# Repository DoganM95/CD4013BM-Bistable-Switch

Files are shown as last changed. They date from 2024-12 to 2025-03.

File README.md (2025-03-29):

# Intro

A pcb with a single button, which on each press toggles a mosfet's output on/off, acting like a mechanical switch. 

## PCB

<table>
  <tr>
    <td>
      PCB Top View
    </td>
    <td>
      PCB Bottom View
    </td>
    <td>
      PCB Top View
    </td>
    <td>
      PCB Top View
    </td>
  </tr>
</table>

## Specs

- Current troughput theoretically: around 10A
- PCB input voltage: 3.0V - 5.0V
- Thicc exposed mosfet traces to create solder wires

## Properties

- Power consumption
  - Switched off:
    - 0.0 uA @ 2.5 V (= less than 100 nA)
    - 4 uA @ 4.2 V
    - 25 uA @ 5.0 V
  - Switched on:
    - 240 uA @ 2.5V
    - 500 uA @ 4.2V
    - 500 uA @ 5.0 V
- Initial state is off
- Two n-channel mosfets in parallel for high current support
- Green status led (optional)
- Debounced button

## BOM
R1: 0805 sized, 10k
R2: 0805 sized, 10k
R3: 0805 sized, 10k
C1: 0805 sized, 100nF
C2: 0805 sized, 100nF
U1: SOIC14 package, CD4013BM
U2: sot23-3 package, AO3400
U3: sot23-3 package, AO3400
S1: Tactile switch CK (Metal shell)
D1: 3528 sized, RGB led with common VCC

## Usage

- Connect e.g. a li-ion battery's GND to the pcb's GND
- Connect li-ion VCC to pcb's VCC
- Connect li-ion VCC to e.g. a motor's VCC
- Connect pcb's DR to motor's GND

## Schematic



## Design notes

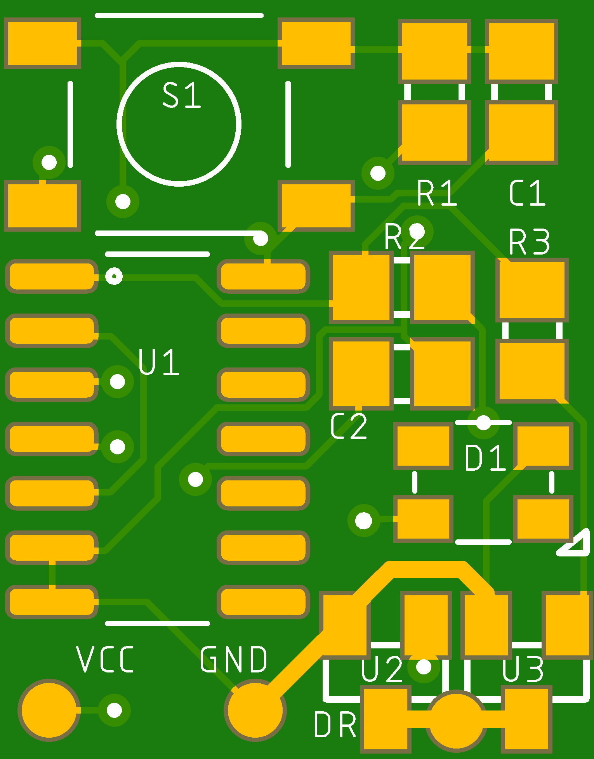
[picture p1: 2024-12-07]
assets/bistable-switch_top.png

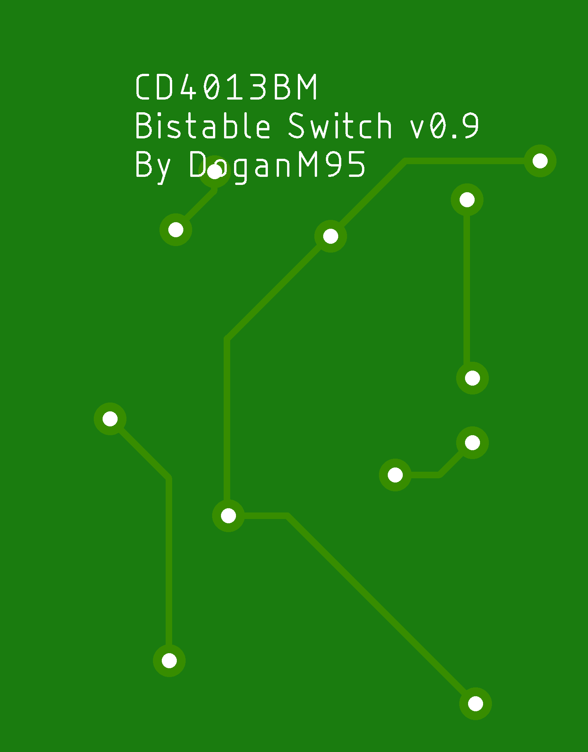
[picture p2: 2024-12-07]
assets/bistable-switch_bottom.png

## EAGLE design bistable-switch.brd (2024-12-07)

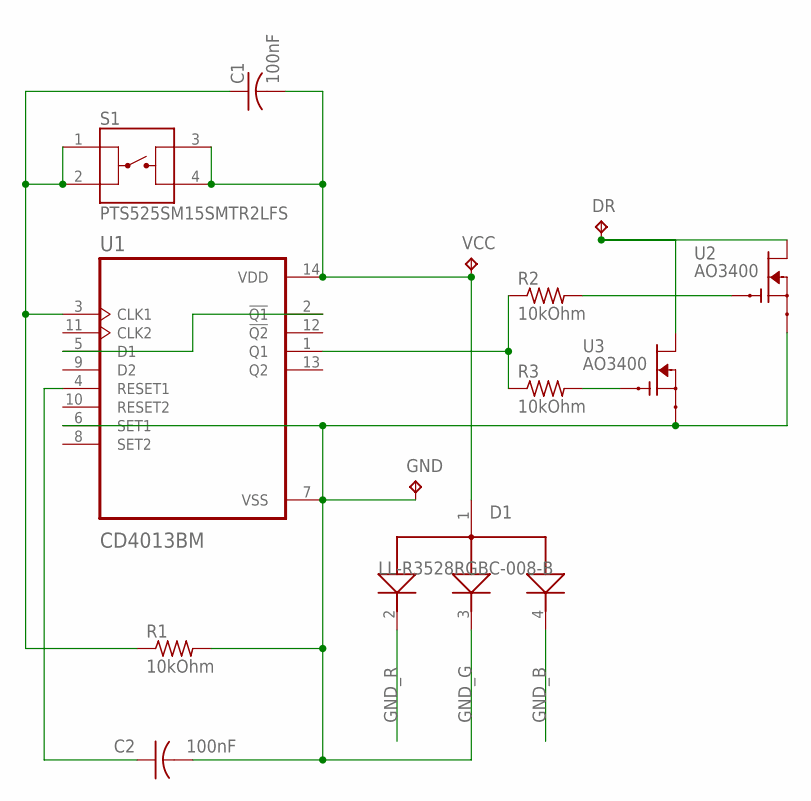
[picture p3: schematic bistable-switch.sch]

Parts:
C1, C2: 100nF; C0805
D1: LL-R3528RGBC-008-B; LED_LL-R3528RGBC-008-B
DR: TPB1,27; B1,27
GND: TPB1,27; B1,27
R1, R2, R3: 10kOhm; R0805
S1: PTS525SM15SMTR2LFS; SW_PTS525SM15SMTR2LFS
U1: CD4013BM; SOIC127P600X175-14N
U2, U3: AO3400; SOT23
VCC: TPB1,27; B1,27

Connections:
CLK1: C1.1, R1.1, S1.1, S1.2, U1.3 (CLK1)
DRAIN: DR.TP, U2.3 (D), U3.3 (D)
GATE_1: R2.2, U2.1 (G)
GATE_2: R3.2, U3.1 (G)
GND_B: D1.4 (CATHODE_BLUE)
GND_G: C2.2, D1.3 (CATHODE_GREEN), GND.TP, R1.2, U1.6 (SET1), U1.7 (VSS), U2.2 (S), U3.2 (S)
GND_R: D1.2 (CATHODE_RED)
unnamed: U1.2 (!Q1), U1.5 (D1)
Q1: R2.1, R3.1, U1.1 (Q1)
RST1: C2.1, U1.4 (RESET1)
VDD: C1.2, D1.1 (COMM_ANODE), S1.3, S1.4, U1.14 (VDD), VCC.TP

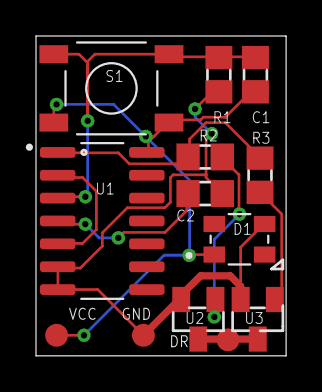
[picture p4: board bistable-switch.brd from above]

Board: 2 copper layers, 13.9 x 17.8 mm, 13 parts (0 on the bottom side), 9 nets.

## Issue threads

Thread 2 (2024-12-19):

Improvements

DoganM95, 2024-12-19:
- Make traces for mosfets thicker
- increase pad-sizes (co sider trough hole)
- add resistor for led
- add led switch jumper (turn enable/disable led)
- debounce button (using a capacitor that is high enough)
- consider using a bigger mosfet (like knd3203) for best performance & more use cases
- switch passive components to 0603 size
- add pads for external switching (shorts button pins)

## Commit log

2024-08-15 init pcb v0.9 (prototype)
    [bistable-switch.brd, bistable-switch.sch]
2024-12-07 update pcb
    [bistable-switch.brd, bistable-switch.sch]
